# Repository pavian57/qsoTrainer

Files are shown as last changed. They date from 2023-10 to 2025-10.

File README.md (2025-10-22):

# Simple cw qsoTrainer by hb9fvk (ruedi) for Arduino 

This is a small program for esp8266 Arduino that creates a cw SOTA qsoTrainer, either as a Chaser or Activator, depending what you give with your paddle.

Entering `**sksk**` goes back to the first step. 

1. As an activator, you start by asking `**qrl?**`, after that you may gon on with cq sota. You are the activator.  

You			: cq sota de xy2abc xy/jo023 k  
qsoTrainer	: xy3cba  
You			: xy3cba gd 559 559 bk  
qsoTrainer	: rr gd 559 559 ref xy/ja134 bk  
You			: 73 tu ee  
qsoTrainer	: xy2ghj

2. If you give a `**kaka**`, the qsoTrainer will act as an Activator, you are the chaser.  

qsoTrainer	: qrl? cq sota de xy3cba xy/ja134 k  
You			: xy2abc  
qsoTrainer	: xy2abc gd 589 589 bk  
You			: rr gd 5nn 5nn ref xy/ja134 73 tu bk  
qsoTrainer	: 73 tu ee  
You			: xy2ghj

3. If you give a `**asas**`, the qsoTrainer will echo everything you give with the paddle.  

give `**asas**` again to leave the trainer mode, the reset button does the same.

4. If you give a `**btbt**`, the qsoTrainer will echo Callsign you give back with the paddle.  

give `**btbt**` again to leave the Callsign mode, the reset button does the same.

5. If you give a `**veve**`, the qsoTrainer will echo CW Abbreviations you give back with the paddle.  

give `**veve**` again to leave the Abbreviation  mode, the reset button does the same.

6. If you give a `**arar**`, the qsoTrainer will echo random character you give back with the paddle.  

give `**arar**` again to leave the character mode, the reset button does the same. Each time you send "ar", it will increase the number of characters, "ba" decreases.

7. to change WPM, Farnsworth, SOTA Mode and Paddle Polarity, doubclick the Black Knob (rotaryeoncoder), to enter Menu, to change a value click once.

## Requirements
It runs on any compatible ESP8266 with a small Oled dispay 0.96".  preferable Wifikit from Heltec. 

I took names.csv from https://hb9sota.ch/names_hb9bin/names.csv, cleaned up a little bit and created a Index on linenumbers for easy access. I did the same to summitslist.csv, that can be downloaded here https://www.sotadata.org.uk/summitslist.csv.

There is not much space for a complete summitlist, i have stripped down to to summit only. As this was'nt enough, i purged all not european countries. 

I made files for all continents.
Summitlist for other Continents ar in the Folder Summits, just copy to data Folder.
If there are no files, random call and summit will be made by the code.

**Software**
- Arduino and VS Code  
- Arduino IDE
- LittleFS

**Hardware**

- ESP8266 Microcontroller , i used Wifikit 8 from Heltec with Oled Display 128x32 I2C  
    https://www.aliexpress.com/w/wholesale-heltec-wifi-kit-8.html?spm=a2g0o.home.search.0
- simple Rotaryencoder 
    https://www.aliexpress.com/w/wholesale-360-Rotary-Encoder.html?spm=a2g0o.detail.search.0
- 3.5mm Jack 3pol female for Paddle and Headset
    https://www.aliexpress.com/w/wholesale-3.5mm-socket.html?spm=a2g0o.productlist.search.0
- 10K Potentiometer
    https://www.aliexpress.com/w/wholesale-RV09-Potentiometer.html?spm=a2g0o.detail.search.0
- 100 Ohm Reistor
- Small Loudspeaker
    https://www.aliexpress.com/w/wholesale-Loudspeaker-1W-8ohm.html?spm=a2g0o.productlist.search.0

## Installation

**LITTTLEFS**
Install LittleFS for access of the Memory on the ESP8266.
Follow these Information.
`https://github.com/esp8266/Arduino`

and these instructions.

`https://randomnerdtutorials.com/install-esp8266-nodemcu-littlefs-arduino/`

**Oled**
get the Oled Library from Github  
`https://github.com/durydevelop/arduino-lib-oled`  

Change line 99 in oled.cpp to  
0xFF, 0xFF, 0xFF, 0xFF, 0xFF, 0xFF, // ~  space   
makes a space instead a ~.  

**source**

First, you have to fetch the source code from GitHub. 

`git clone https://github.com/pavian57/qsoTrainer`

You can also download a ZIP file from Github

`Code -> Download ZIP`

and unzip it.

### ESP8266
Use the Arduino IDE or VS Code

## Set-up

1. Connect the ESP8266, setup SPIFFS and upload data directory.   
2. Upload Sketch.  
3. connect paddle and headset and start exploring qsoTrainer

## Logging

To see what you are keying, connect a Serial Terminal or use a Tablet and connect to WifiAp = qsoTrainer no Password, us a Telneclient to listen to 192.168.4.22:8088, i use ConnectBot for Android. 
https://play.google.com/store/apps/details?id=org.connectbot&hl=en_US

## Future Improvements

## Contact and Community

73 de hb9fvk (ruedi)

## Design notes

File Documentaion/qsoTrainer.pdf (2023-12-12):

QsoTrainer © by HB9FVK

The intention to make a cw Trainingsdevice was a Project to find out, if such a device could be made by myself.

It is mainly to train qso, you make qso with an esp8266 microcontroller with a small oled screen. 128X32. You can control the qsoTrainer mostly by giving a special cw pro signs, such as listed below. Given the pro signs a second time, the mode will be terminated and confirmed by “rr”.

twice SK will reset the qsoTrainer.
<sk><sk> | Reset

the next commands starts a qso, either as caller or answerer, in SOTA Mode, you will be the chaser or the Activator.
<ka><ka> | Chaser mode
<qrl?> | Activator mode

A qso follows these rules. [SOTA] depends if SOTA mode or not, default is non SOTA.

Activator: CQ [SOTA] DE XY2ABC [XY/KB023] K
Chaser : XY2DEF
Activator: XY2DEF GD 559 559 BK
Chaser : RR GD 559 559 [REF XY/KB045] 73 TU BK Activator: 73 TU EE
Chaser : XY2GHJ

Echos every code you give with your paddle.

<as><as> | Trainingsmode keying

The following modes are to practice cw, by listening to cw and giving back what you heard. After 5 fails, the code will be given again.

<bt><bt> | Call sign Training
<ve><ve> | CW Abbreviation Training
<ar><ar> | single character Training.

Menu system

Double click the Encoder Knob (right side) for the Menu, select WPM, Farnsworht, SOTA mode or paddle Polarity.

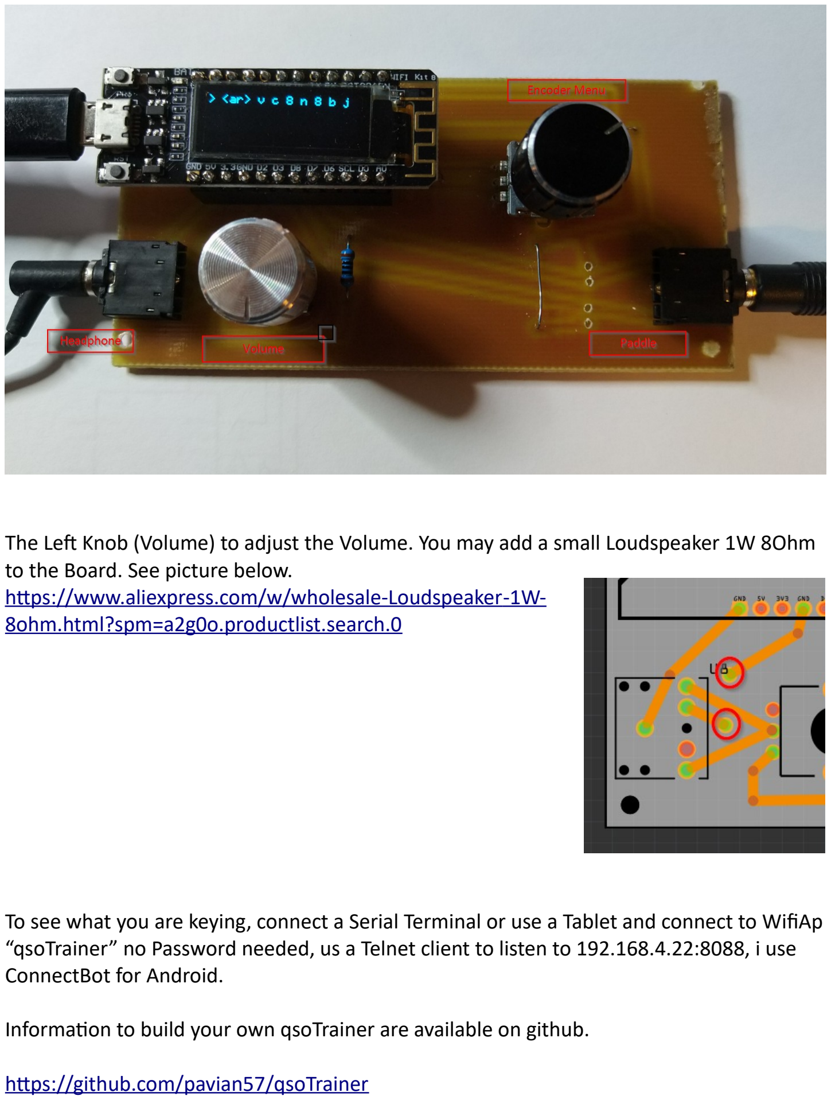
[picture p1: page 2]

The Left Knob (Volume) to adjust the Volume. You may add a small Loudspeaker 1W 8Ohm to the Board. See picture below.
https://www.aliexpress.com/w/wholesale-Loudspeaker -1W-8ohm.html?spm=a2g0o.productlist.search.0

To see what you are keying, connect a Serial Terminal or use a Tablet and connect to WifiAp “qsoTrainer” no Password needed, us a Telnet client to listen to 192.168.4.22:8088, i use ConnectBot for Android.

Information to build your own qsoTrainer are available on github.

https://github.com/pavian57/qsoTrainer

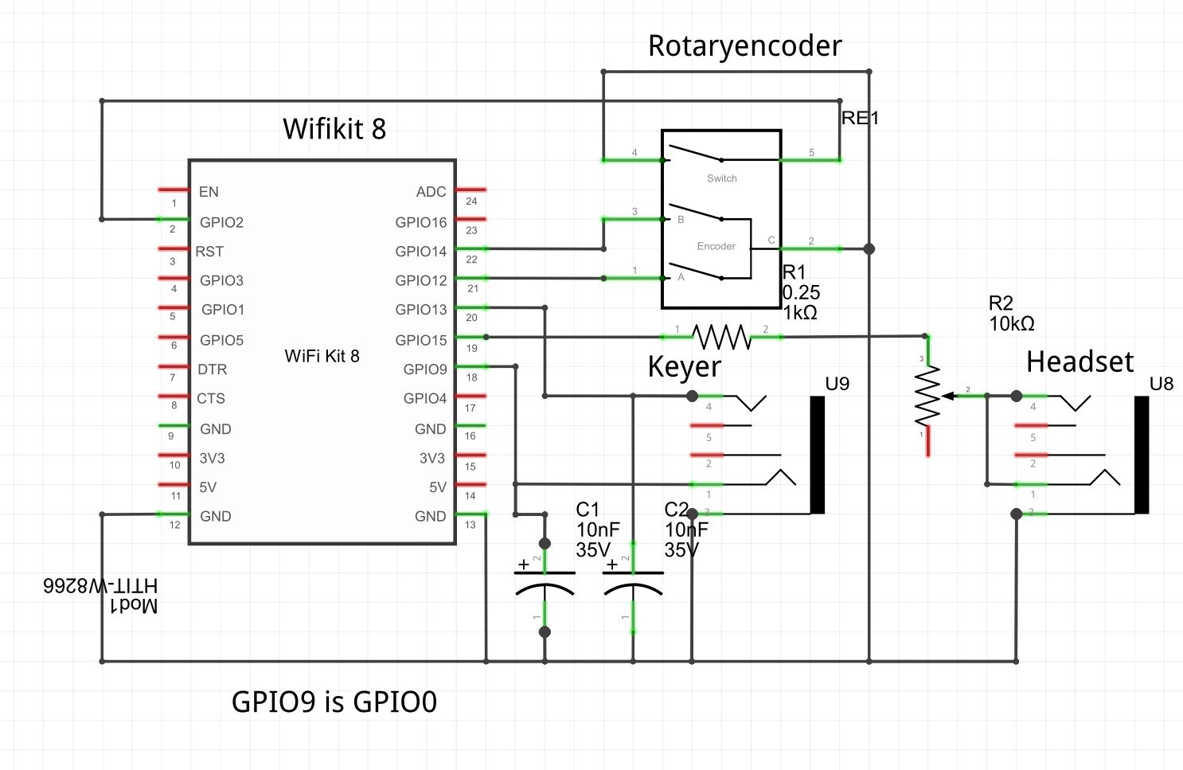
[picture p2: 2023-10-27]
Documentaion/qsoTrainer.jpg

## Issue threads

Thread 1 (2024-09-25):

The code format is very standardized, beautiful, and very easy to read.

bi3qwq, 2024-09-25:
The code format is very standardized, beautiful, and very easy to read.

Thanks @pavian57 .

great job!

pavian57, 2024-09-26:
thank you

have a nice day

bi3qwq, 2024-09-26:
您的邮件我已经收到，这里是BI3QWQ。

Closed 2024-09-26.

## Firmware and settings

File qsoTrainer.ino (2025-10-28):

#include <Arduino.h>

#include <EEPROM.h>

// https://github.com/LennartHennigs/
#include <Button2.h>
#include <ESPRotary.h>

#define USE_LittleFS

// #include <FS.h>
#include <LittleFS.h>


#include "Morse.h"
#include "Display.h"

using namespace qsoTrainer;

#define Version 1.0b


#define P_DOT    13   // Connects to the dot lever of the paddle
#define P_DASH   00   // Connects to the dash lever of the paddle

#define P_UP  14  //sda
#define P_DOWN  12  //scl
#define P_BUTTON 02  //d3

#define P_AUDIO    15 // Audio output

#define CLICKS_PER_STEP   4   // this number depends on your rotary encoder 

#define DIT_L    0x01 // Dit latch
#define DASH_L   0x02 // Dash latch
#define DIT_PROC 0x04 // Dit is being processed
#define IAMBICA  0x00 // 0: Iambic A, 1: Iambic B
#define IAMBICB  0x10 // 0: Iambic A, 1: Iambic B

enum KSTYPE {IDLE, CHK_DIT, CHK_DASH, KEYED_PREP, KEYED, INTER_ELEMENT };

int actualWpm = 18; // = 20;  5 - 50
int actualFarnsWpm = 5; // = 10; 0-10

int actualWpmPrev; // = 20;  5 - 50
int actualFarnsWpmPrev; // = 10; 0-10

int sotaqso = 0; // no sota
int paddlepolarity = 0; // 0 = . Left, 1 = - Left
int iambicab = 0; // 0 = A, 1 = B
int frequency = 1;
int eepromused = 99;


int ditState = 0;        
int dahState = 0;
int LastElement = 0;



int elementLengthMs;
int elementLengthMsFarns;

unsigned long previousMillis = 0 ;
unsigned long currentMillis;

unsigned char keyerControl, keyerState;
unsigned long interWordTimer = 0;
unsigned long interCharTimer = 0;


String actSign;
String actWord;
String txtSign;
String cwAbbr;

int menuitem = 1;
int lastMenuItem = 1;


int page = 1;

bool inMenu = false;
bool chvalue = false;
bool abbrAvailable = false;




int mode = 1;
int farnsworth = 2;


Button2 button; 
ESPRotary rotary;


Morse morse(P_AUDIO);



void update_PaddleLatch() {
  if (paddlepolarity) {
    if (digitalRead(P_DASH) == LOW) keyerControl |= DIT_L;  // DITS   on TIP ( Stereo Plug )
    if (digitalRead(P_DOT) == LOW) keyerControl |= DASH_L; // DASHES on RING ( Stereo Plug )
  } else {
    if (digitalRead(P_DOT) == LOW) keyerControl |= DIT_L;  // DITS   on TIP ( Stereo Plug )
    if (digitalRead(P_DASH) == LOW) keyerControl |= DASH_L; // DASHES on RING ( Stereo Plug )
  }
}


// Initializing the Arduino
void setup() {
  Serial.begin(115200);
  delay(2000);
  
  interCharTimer = 4294967000;                       // almost the biggest possible unsigned long number :-) - do not output extra spaces!                       
  interWordTimer = 4294967000; 
  
  
  pinMode(P_DOT, INPUT_PULLUP);
  pinMode(P_DASH, INPUT_PULLUP); 

  keyerState   = IDLE;
 
  rotary.begin(P_DOWN, P_UP, CLICKS_PER_STEP);
  rotary.setChangedHandler(rotate);

  button.begin(P_BUTTON);
  button.setClickHandler(singleClick);
  button.setDoubleClickHandler(doubleClick);

  actSign = "";
  actWord = "";
  qsoDisplay::initDisplay(); // Init Display
  
  currentMillis = millis();
  
  Serial.println();
  if (morse.LittleFSActive) {
    Serial.println("LittleFS Active");
  } else {
    Serial.println("Unable to activate LittleFS");
  }

  int addr=0;
  // addr = writeToEeprom();

  
  EEPROM.begin(512);
  EEPROM.get(addr, eepromused);
  addr += sizeof(eepromused);
  Serial.println(eepromused);
  if (eepromused == 99) {
    EEPROM.get(addr, actualWpm);
    addr += sizeof(actualWpm);
    EEPROM.get(addr, actualFarnsWpm);
    addr += sizeof(actualFarnsWpm);
    EEPROM.get(addr, sotaqso);
    addr += sizeof(sotaqso);
    EEPROM.get(addr, paddlepolarity);
    addr += sizeof(paddlepolarity);
    EEPROM.get(addr, iambicab);
    addr += sizeof(iambicab);
    EEPROM.get(addr, frequency);  
  }
  EEPROM.end();
  
  


  morse.sotaqso = sotaqso;
  morse.frequency = frequency;
  
  if (actualWpm < 5 || actualWpm > 61) {
    actualWpm = 20;
    actualFarnsWpm = 0;
  }

  Serial.println();
  Serial.println("Setup CW Speed");
  updateWpm();
  
  Serial.printf("Sota mode %d\n",sotaqso);    
  Serial.printf("Polarity  %d\n",paddlepolarity);
  Serial.printf("Iambic B mode %d\n",iambicab);
  Serial.printf("Frequency  %d\n",frequency);  
  Serial.printf("Frequency  Hz %d\n",morse.frequencys[morse.frequency]);
  
  

  if (iambicab == 0) {
      keyerControl = IAMBICA;
  } else {
      keyerControl = IAMBICB;
  }
  int freq = morse.frequencys[frequency];    
  qsoDisplay::intro(actualWpm,actualFarnsWpm, sotaqso,paddlepolarity,iambicab, freq);  
  qsoDisplay::addString(">");
  Serial.println("done");
}

// Main routine
void loop()
{
  static long ktimer;
  static long ctimer;
  

  rotary.loop();
  button.loop();
  

  qsoDisplay::handleTelnet();


  

  if ( mode == 1 ) {
    
    
    currentMillis = millis();

  switch (keyerState) { 
    
    case IDLE: if (millis() > interCharTimer) {             
             actSign.concat(" ");            
             txtSign = morse.encode(actSign);
             actWord.concat(txtSign);           
             Serial.print(actSign);             
             actSign.clear();             
             interCharTimer = 4294967000;                       // almost the biggest possible unsigned long number :-) - do not output extra spaces!             
          }
          if (millis() > interWordTimer) {
            morse.tlg = actWord;
            Serial.println(actWord);
            if (actWord == "//?") {                             
              int freq = morse.frequencys[frequency];
              qsoDisplay::intro(actualWpm,actualFarnsWpm,morse.sotaqso,paddlepolarity,iambicab, freq);
              qsoDisplay::addString(">");
              actWord.clear();  
            } else {          
              morse.doQso();
            
              Serial.print("State: "); Serial.print(morse.State);
              Serial.print(" Type: "); Serial.println(morse.Type);  
        
              if (!morse.nextStep){
                qsoDisplay::printTelnet(actWord);
              }               
              actWord.clear();  
              interWordTimer = 4294967000;                       // almost the biggest possible unsigned long number :-) - do not output extra spaces!             
            }
          }

              
              if ((digitalRead(P_DOT) == LOW) || (digitalRead(P_DASH) == LOW) || (keyerControl & 0x03)) {
                 update_PaddleLatch(); 
                 keyerState = CHK_DIT; 
               } 
             
               break;
 
    case CHK_DIT: if (keyerControl & DIT_L) { 
                    keyerControl |= DIT_PROC;
                    // Some of PP5VX's fingers are here...
                    // ktimer = ditTime;    // If you don't use Weight Control
                    ktimer = elementLengthMs;     // Dit Time+Weight
                    
                    keyerState = KEYED_PREP;
                    //Serial.print(".");
                    actSign.concat(".");
                  } else keyerState = CHK_DASH;
                  break;
 
    case CHK_DASH: if (keyerControl & DASH_L) { // Some of PP5VX's fingers are here...
                   
                     ktimer = elementLengthMs*3; // Dash Time+Weight                                         
                     //Serial.print("-");
                     actSign.concat("-");
                     keyerState = KEYED_PREP; 
                   } else keyerState = IDLE;
                  break;
 
    case KEYED_PREP: 
                     //tone(ST_Pin, key_tone);                     
                     ktimer += millis();
                     keyerControl &= ~(DIT_L + DASH_L);
                     keyerState = KEYED;
                     morse.cwOn();
                     break;
 
    case KEYED: if (millis() > ktimer) { 
                  morse.cwOff();
                  
                  //noTone(ST_Pin);                                    
                  ktimer = millis()+elementLengthMs;  
                  keyerState = INTER_ELEMENT; 
                  interWordTimer = millis() + 7*elementLengthMs;
                  interCharTimer = millis() + 2*elementLengthMs;
                } else if (keyerControl & IAMBICB) {
                  update_PaddleLatch();
                }                
                break;
 
    case INTER_ELEMENT: update_PaddleLatch();
                  //      interWordTimer = millis() + 2*ditTime;
                        if (millis() > ktimer) { 
                          
                          if (keyerControl & DIT_PROC) {  
                            keyerControl &= ~(DIT_L + DIT_PROC);
                            keyerState = CHK_DASH; 
                          } else  { keyerControl &= ~(DASH_L);
                            keyerState = IDLE;                                    
                          }
                        } 
                      
                        
                        
                        
                        break;
  } // end Case






  
  }
}

/*
 * Calculate dit length in milliseconds from WPM
 */

void updateWpm()
{

  elementLengthMs = 1200 / actualWpm;
  morse.dotLength = elementLengthMs;
  Serial.print("elementLengthMs: ");
  Serial.println(elementLengthMs);

  
  if (actualFarnsWpm > 0) {
    if (actualWpm >= actualFarnsWpm) exit;
    elementLengthMsFarns = 1200 / (actualWpm - actualFarnsWpm );
    Serial.print("elementLengthMsFarns: ");
    morse.farnsLength = elementLengthMsFarns;  
    Serial.println(elementLengthMsFarns);
    morse.useFansw = true;
  }

  morse.dotLength = elementLengthMs;
  morse.farnsLength = elementLengthMsFarns;
  
  
}


int writeToEeprom(){
  /*Serial.println("Save all to EEPROM!");
  Serial.println("--------------------1-------------------------");
  Serial.printf("actual WPM %d\n",actualWpm);
  Serial.printf("Setting Farnsworth to %d\n",actualFarnsWpm);
  Serial.printf("Sota mode %d\n",sotaqso);  
  Serial.printf("Sota mode morse %d\n",morse.sotaqso);  
  Serial.printf("Polarity  %d\n",paddlepolarity);
  Serial.printf("Iambic B mode %d\n",iambicab);
  Serial.printf("Frequency  %d\n",frequency);
  Serial.printf("Frequency morse %d\n",morse.frequency);
  Serial.printf("Frequency HZ %d\n",morse.frequencys[morse.frequency]);*/

  int addr=0;
  EEPROM.begin(512);  
  EEPROM.put(addr, eepromused);
  addr += sizeof(eepromused);
  EEPROM.put(addr, actualWpm);
  addr += sizeof(actualWpm);
  EEPROM.put(addr, actualFarnsWpm);
  addr += sizeof(actualFarnsWpm);
  EEPROM.put(addr, sotaqso);
  addr += sizeof(sotaqso);
  EEPROM.put(addr, paddlepolarity);
  addr += sizeof(paddlepolarity);
  EEPROM.put(addr, iambicab);
  addr += sizeof(iambicab);
  EEPROM.put(addr, frequency);  
  boolean rc = EEPROM.commit();
  EEPROM.end();

  /*Serial.println("--------------------2-------------------------");
  Serial.printf("EEprom commit variable is: %s\n", rc ? "true" : "false");  
  Serial.printf("actual WPM %d\n",actualWpm);
  Serial.printf("Setting Farnsworth to %d\n",actualFarnsWpm);
  Serial.printf("Sota mode %d\n",sotaqso);  
  Serial.printf("Sota mode morse %d\n",morse.sotaqso);  
  Serial.printf("Polarity  %d\n",paddlepolarity);
  Serial.printf("Iambic B mode %d\n",iambicab);
  Serial.printf("Frequency  %d\n",frequency);
  Serial.printf("Frequency morse %d\n",morse.frequency);
  Serial.printf("Frequency HZ %d\n",morse.frequencys[morse.frequency]);*/

  

  /*addr=0;
  EEPROM.begin(512);
  actualWpm =   EEPROM.read(addr);
  actualFarnsWpm = EEPROM.read(addr+sizeof(uint8_t));
  sotaqso = EEPROM.read(addr+sizeof(uint8_t));
  paddlepolarity = EEPROM.read(addr+sizeof(uint8_t));
  iambicab = EEPROM.read(addr+sizeof(uint8_t));
  frequency = EEPROM.read(addr+sizeof(uint8_t));  
  EEPROM.end();


  Serial.println("--------------------3-------------------------");
  Serial.printf("actual WPM %d\n",actualWpm);
  Serial.printf("Setting Farnsworth to %d\n",actualFarnsWpm);
  Serial.printf("Sota mode %d\n",sotaqso);  
  Serial.printf("Sota mode morse %d\n",morse.sotaqso);  
  Serial.printf("Polarity  %d\n",paddlepolarity);
  Serial.printf("Iambic B mode %d\n",iambicab);
  Serial.printf("Frequency  %d\n",frequency);
  Serial.printf("Frequency morse %d\n",morse.frequency);
  Serial.printf("Frequency HZ %d\n",morse.frequencys[morse.frequency]);
  Serial.println("----------------------------------------------");*/

  return 1;
}




void doubleClick(Button2& btn) {
  Serial.println("doubleclick:  ");
  if (mode == 2) { 
    qsoDisplay::clearMenu();    
    updateWpm();
    int i = writeToEeprom();
    mode = 1;
    inMenu = false;
  } else {
    mode = 2;
    inMenu = true;
    menuitem = 1;
    lastMenuItem = 1;  
    qsoDisplay::prepareMenu();
    qsoDisplay::printMenu(page, actualWpm, actualFarnsWpm, morse.sotaqso);    
    rotary.setUpperBound(7);
    rotary.setLowerBound(0);
    rotary.resetPosition(1,false);
  }
 
}

void singleClick(Button2& btn) {

  if (inMenu) {    
    if (chvalue) {            
      rotary.setUpperBound(7);
      rotary.setLowerBound(0);
      rotary.resetPosition(menuitem,false);
      qsoDisplay::resetMenuPointertoValues(menuitem);
      chvalue = false;
    } else {
      chvalue = true;      
      switch(menuitem){
         case 1: 
            rotary.setUpperBound(51);
            rotary.setLowerBound(4);
            rotary.resetPosition(actualWpm,false);
            qsoDisplay::setMenuPointertoValues(1);
          break;
          case 2:
            rotary.setUpperBound(11);
            rotary.setLowerBound(-1);
            rotary.resetPosition(actualFarnsWpm,false);                        
            qsoDisplay::setMenuPointertoValues(2);
          break;
          case 3:
            qsoDisplay::setMenuPointertoValues(3);            
            break;
          case 4:                                  
            qsoDisplay::setMenuPointertoValues(4);
          break;
          case 5:            
            qsoDisplay::setMenuPointertoValues(5);
          break;
          case 6:
            rotary.setUpperBound(5);
            rotary.setLowerBound(-1);
            rotary.resetPosition(frequency,false);  
            qsoDisplay::setMenuPointertoValues(6);            
          break;
        default: break;                     
     }
    }   
  }
  Serial.println("click:  "); 
}

  /*String menu1 = "WPM";
  String menu2 = "Farnsworth";
  String menu3 = "SOTA Mode";
  String menu4 = "Paddle Polarity";
  String menu5 = "IAMBIC B";*/

void rotate(ESPRotary& r) {

  if (inMenu && !chvalue) {
    lastMenuItem = menuitem;
    menuitem = rotary.getPosition();   
    if (menuitem >= 4) {   
      if (page != 2) {
        qsoDisplay::prepareMenu();        
        qsoDisplay::printMenu(2, paddlepolarity, iambicab, morse.frequencys[frequency]);            
      }
      page = 2;                  
    } else {      
      if (page != 1) {
        qsoDisplay::prepareMenu();
        qsoDisplay::printMenu(1, actualWpm, actualFarnsWpm, morse.sotaqso);        
      }
      page = 1;            
    }  
    qsoDisplay::updateMenu(page, menuitem,lastMenuItem);      
  } 

  if (inMenu && chvalue ) {    
    if (menuitem == 1) {           
        actualWpm = rotary.getPosition();
        qsoDisplay::updateValues(1,actualWpm);         
    } else if (menuitem == 2){ 
        actualFarnsWpm = rotary.getPosition();
        qsoDisplay::updateValues(10,actualFarnsWpm); 
    } else if (menuitem == 3) { 
        sotaqso = morse.sotaqso;        
        sotaqso =  (sotaqso == 0) ? 1 : 0;
        qsoDisplay::updateValues2d(19,sotaqso); 
        morse.sotaqso = sotaqso;            
    } else if (menuitem == 4){ 
        paddlepolarity =  (paddlepolarity == 0) ? 1 : 0;        
        qsoDisplay::updateValues2d(1,paddlepolarity);                 
    } else if (menuitem == 5) {         
        iambicab =  (iambicab == 0) ? 1 : 0;
        qsoDisplay::updateValues2d(10,iambicab);                
    } else if (menuitem == 6) {                   
        frequency = rotary.getPosition();              
        int freq = morse.frequencys[frequency];  
        qsoDisplay::updateValues3d(19,freq); 
        morse.frequency = frequency; 
        
    }
  }

     

  Serial.println("-----------------------------------------");
  Serial.print("menuitem: ");
  Serial.println(menuitem);

  Serial.print("lastMenuItem: ");
  Serial.println(lastMenuItem);   

 
  Serial.print("page: ");
  Serial.println(page);

  
  
}

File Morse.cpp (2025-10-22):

/*
  Morse.cpp - Library for flashing Morse code.
  Created by David A. Mellis, November 2, 2007.
  Released into the public domain.
*/

#include <Arduino.h>
#include <LittleFS.h>
#include "Display.h"
#include "Morse.h"

namespace qsoTrainer
{

  Morse::Morse(int soundPin)
  {
    pinMode(soundPin, OUTPUT);
    _soundPin = soundPin;
    useFansw = 0;
    farnsLength = 0; // 5 = 240ms 6 = 200ms 7 = 141ms
    dotLength = 75;  //16wpm
    State = NADA;
    Type = NONE;
    _calllength = 6;
    _repeats = 1;
    sotaqso = false;
    randomSeed(RANDOM_REG32);   
    if (LittleFS.begin()) {
      LittleFSActive = true;
    }
  }

  void Morse::cwOn()
  {
    tone(_soundPin, frequencys[frequency]);    
  }

  void Morse::cwOff()
  {    
    noTone(_soundPin);
  }

  void Morse::dot()
  {
    tone(_soundPin, frequencys[frequency]);
    delay(dotLength);
    noTone(_soundPin);
    delay(dotLength);
  }

  void Morse::dash()
  {
    tone(_soundPin, frequencys[frequency]);
    delay(dotLength * 3);
    noTone(_soundPin);
    delay(dotLength);
  }

  String Morse::decode(String text)
  {
    int i;
    int j;
    String code = "";
    for (i = 0; text[i]; ++i) {
      for (j = 0; j < sizeof MorseMap / sizeof *MorseMap; ++j) {
        if (tolower(text[i]) == MorseMap[j].letter)
        {
          code += MorseMap[j].code;
          break;
        }
      }
      code += " "; //Add tailing space to seperate the chars
    }
    return code;
  }

  String Morse::encode(String code)
  {
    String msg = "";
    code.trim();
    if (code == "...-.-")
    {
      return "<sk>";
    }
    if (code == "-.-.-")
    {
      return "<ka>";
    }

    if (code == ".-...")
    {
      return "<as>";
    }
    if (code == "-...-")
    {
      return "<bt>";
    }
    if (code == "...-.")
    {
      return "<ve>";
    }
    if (code == ".-.-.")
    {
      return "<ar>";
    }
    if (code == "-....-")
    {
      return "<ba>";
    }


    /*
      Pro signs 
               <as> .-...
               <ka> -.-.-
               <kn> -.--.
               <sk> ...-.-
               <ve> ...-.
               <bt> -...-
               <ar> .-.-.
               <hh> ........
               <cl> -.-.
    */
      
               
    code.concat(" ");
    int lastPos = 0;
    int pos = code.indexOf(' ');
    while (lastPos <= code.lastIndexOf(' '))
    {
      for (int i = 0; i < sizeof MorseMap / sizeof *MorseMap; ++i)
      {
        if (code.substring(lastPos, pos) == MorseMap[i].code)
        {
          msg += MorseMap[i].letter;
        }
      }

      lastPos = pos + 1;
      pos = code.indexOf(' ', lastPos);

      // Handle white-spaces between words (7 spaces)
      while (code[lastPos] == ' ' && code[pos + 1] == ' ')
      {
        pos++;
      }
    }

    return msg;
  }

  void Morse::sendCode(String text)
  {
    String code;
    text.trim();
    Serial.println(text);
    code = decode(text);
    Serial.println(code);
    for (int i = 0; code[i]; i++)
    {
      switch (code[i])
      {
      case '.': //dit
        dot();
        break;

      case '-': //dah
        dash();
        break;

      case ' ': //gap
        if (farnsLength == 0)
        {
          delay(dotLength * 3);
        }
        else
        {
          delay(farnsLength * 3);
        }
      }
    }
    /*if (farnsLength == 0)
    {
      delay(dotLength * 7);
    }
    else
    {
      delay(farnsLength * 7);
    }*/
  }

  String Morse::randomcwChar(){
    int i = 0;
    //Serial.printf("numChars %d\n",_numChars);

    if (_numChars == 1) {
      _ourChar =  MorseMap[random(0, 36)].letter;
      return _ourChar;
    } else {
      _ourChar.clear();
    }
    while (i < _numChars) {
        _ourChar += MorseMap[random(0, 36)].letter;
        i++;
      }
    
    return _ourChar;
    //callsign += MorseMap[random(26, 35)].letter;  
  }

  String Morse::randomcwAbbr(){
    int i = 0;
    char idxbuffer[64]; //declare a buffer - hopefully this speeds things up...
    long fsize = 0;
    long randNumber;
    
    if (LittleFS.exists(F("/abbr.idx"))  &&  LittleFSActive) {
      File f1 = LittleFS.open("/abbr.txt", "r");
      File fx = LittleFS.open("/abbr.idx", "r");
      
      fsize = fx.size();
      randNumber = random(0, (fsize / 8) - 1);

      fx.seek(randNumber * 8);
      fx.read((byte *)&_idx, 8);

      f1.seek(_idx.pos);
      int l = f1.readBytesUntil(' ', idxbuffer, sizeof(idxbuffer));
      idxbuffer[l] = 0;
      _ourAbbr = String(idxbuffer);
      _ourAbbr.toLowerCase();
      
      fx.close();
      f1.close();
      return _ourAbbr;
    } else {
      return "no abbreviation found";
    }
  }
  

  String Morse::randomCall()
  {
    int i = 0;
    char idxbuffer[64]; //declare a buffer - hopefully this speeds things up...
    long fsize = 0;
    long randNumber;
    
    if (!LittleFS.exists(F("/names.idx"))  &&  LittleFSActive)
    {
     
      String callsign;
      callsign += MorseMap[random(0, 27)].letter;
      callsign += MorseMap[random(0, 27)].letter;
      callsign += MorseMap[random(26, 36)].letter;
      while (i < 3) {
        callsign += MorseMap[random(0, 27)].letter;
        i++;
      }
      return callsign;
    }
    else
    {
      File f1 = LittleFS.open("/names.txt", "r");
      File fx = LittleFS.open("/names.idx", "r");
      
      fsize = fx.size();
      randNumber = random(0, (fsize / 8) - 1);

      fx.seek(randNumber * 8);
      fx.read((byte *)&_idx, 8);

      f1.seek(_idx.pos);
      int l = f1.readBytesUntil(',', idxbuffer, sizeof(idxbuffer));
      idxbuffer[l] = 0;
      _ourCall = String(idxbuffer);
      _ourCall.toLowerCase();
      l = f1.readBytesUntil('\n', idxbuffer, sizeof(idxbuffer));
      idxbuffer[l] = 0;
      _ourName = String(idxbuffer);
      fx.close();
      f1.close();
      return _ourCall;
    }
  }

  String Morse::randomRST()
  {
    int i = 0;
    
    String rst = "";
    rst += MorseMap[random(27, 31)].letter;
    rst += MorseMap[random(27, 36)].letter;
    rst += MorseMap[random(27, 36)].letter;
    return rst;
  }

  String Morse::randomSummit()
  {
    int i = 0;
    char idxbuffer[64]; //declare a buffer - hopefully this speeds things up...
    long fsize = 0;
    long randNumber;
    String summit = "";
    if (!LittleFS.exists(F("/summitslist.idx"))  &&  LittleFSActive){
      summit += MorseMap[random(0, 27)].letter;
      summit += MorseMap[random(0, 27)].letter;
      summit += "/";
      summit += MorseMap[random(0, 27)].letter;
      summit += MorseMap[random(0, 27)].letter;
      while (i < 3) {
        summit += MorseMap[random(26, 36)].letter;
        i++;
      }
      return summit;
    } else {
      File f1 = LittleFS.open("/summitslist.txt", "r");
      File fx = LittleFS.open("/summitslist.idx", "r");
      
      fsize = fx.size();
      randNumber = random(0, (fsize / 8) - 1);

      fx.seek(randNumber * 8);
      fx.read((byte *)&_idx, 8);
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

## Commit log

2021-11-20 Telnet does print double, flag disables
2023-09-22 input 0 shall not be gnd for programming and boot up
2023-09-25 removed buttons, new rotary encoder
2023-10-23 change on pcb wrong
    [qsoTrainer.ino]
2023-10-26 reset actual mode, add ee again
    [Morse.cpp]
2023-10-27 missing connection on headset
    [qsoTrainer.fzz]
2023-10-27 moved docu to documentaion
    [qsoTrainer.fzz]
2023-11-16 display was wrong, is okay no
    [Display.cpp]
2023-12-05 calc of farns speed was wrong
    [qsoTrainer.ino]
2024-06-21 show char after given correct
    [Morse.cpp]
